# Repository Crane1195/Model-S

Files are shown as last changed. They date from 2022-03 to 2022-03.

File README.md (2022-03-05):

# Model-S
This circuit board is a complete solution for making custom all digital GameCube controllers without soldering.

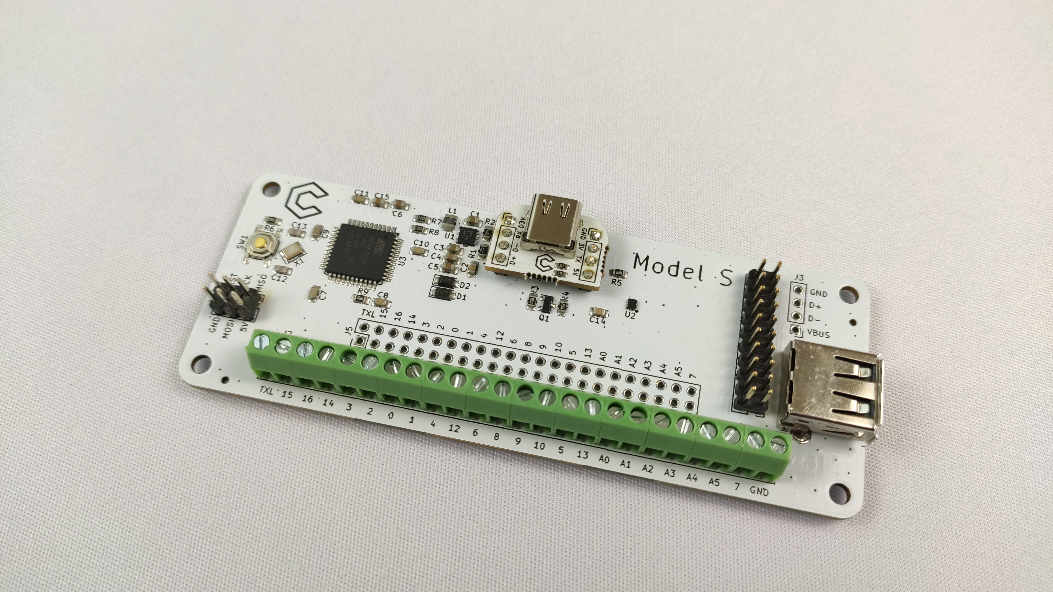
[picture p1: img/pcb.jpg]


## Features
- Connects to GameCube/Wii/GCC to USB adapter using the USB-C to GameCube cables that are sold on the Frame1 and the B0XX websites
- Connect buttons with screw terminals or 2.54mm pitch through holes
- Easily connect to a Brook Board to use the controller on PlayStation/Xbox/other consoles, with both boards sharing the Model S USB-C port
- Can be powered with just 3.3V, allowing the board to work on Mayflash adapters without the gray USB cable as well as GameCube/Wii consoles with faulty rumble lines

## Resources

User Manual - https://www.craneslab.xyz/manuals/s

Firmware - https://github.com/Crane1195/CL-FW

Questions - https://craneslab.xyz/discord

## License
This project is licenced under the GNU GPL Version 3. [See the included LICENSE file for details](LICENSE).

## Support my work
I set up a donation link for people who appreciate my work and wish to donate. Donations are greatly appreciated, but are far from necessary:

https://www.paypal.com/donate/?hosted_button_id=NFDEML5FKR8N8

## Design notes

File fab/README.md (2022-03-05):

# Disclaimer

I used JLC to assemble these circuit boards, but they have made mistakes on every single batch.

On the final batch that I will ever make with them, 240 Model S v2.3's, they ruined 142 of them.

JLC made several incorrect excuses as to why it was my fault, and refused to refund me. After two months of debating and gathering evidence, I got most of the money back through a PayPal dispute.

I will have the gerber/BOM/CPL files here for informational purposes only, but I do not advise using JLC.

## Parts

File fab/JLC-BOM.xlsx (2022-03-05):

Comment | Designator | Footprint | LCSC Part #
22uF | C1, C3-5 | 0805 | C45783
10nF | C2 | 0805 | C1710
4.7uF | C6 | 0805 | C1779
100nF | C7-11, C14 | 0805 | C49678
22pF | C12, C13 | 0805 | C1804
1uF | C15 | 0805 | C28323
MBR120 | D1, D2 | SOD-123 | C130880
1x4 Pin Headers | J1, J8 | HDR-TH_4P-P2.54-V | C124378
USB-A Female | J2 | USB-A-TH_USB-M-1_C2346 | C2346
2x3 Pin Headers | J4 | HDR-TH_6P-P2.54-V-R2-C3-S2.54 | C65114
2x10 Pin Headers | J6 | HDR-TH_20P-P2.54-V-M-R2-C10-S2.54 | C124359
Screw Terminals | J9-14 | CONN-TH_XY350V-3.5-4P | C557656
1uH | L1 | L2520 | C171753
BSS138 | Q1 | SOT-23-3 | C400505
402KΩ | R1 | 0805 | C17680
100KΩ | R2 | 0805 | C17407
10KΩ | R3-6, R9 | 0805 | C17414
22Ω | R7, R8 | 0805 | C17561
SW_PUSH | SW1 | SMD-SW-4_5.1x5.1x1.5 | C318884
TPS61230DRCR | U1 | VSON-10_EP_3.0x3.0x0.5P | C139626
TS3USB30ERSWR | U2 | UQFN-10_1.4x1.8x0.4P | C73880
ATMEGA32U4-AU | U3 | QFP-44_10.0x10.0x0.8P | C44854
16 Mhz XTAL | X1 | SMD-3225_4P | C70562

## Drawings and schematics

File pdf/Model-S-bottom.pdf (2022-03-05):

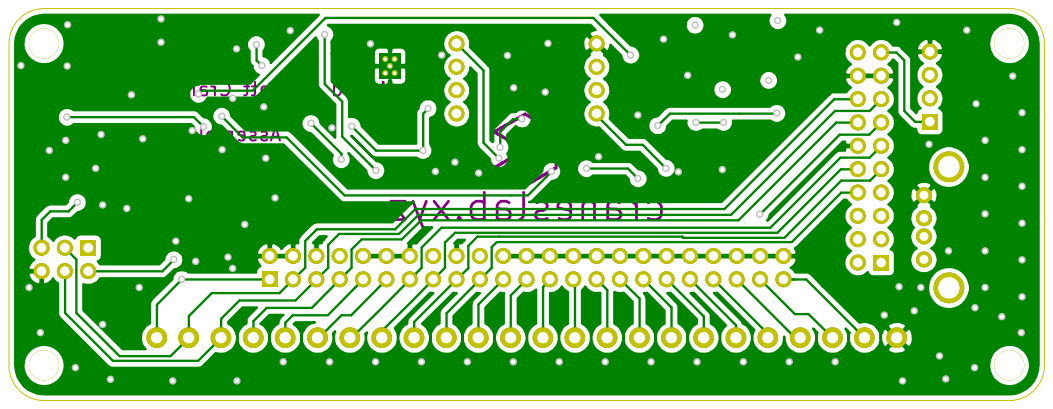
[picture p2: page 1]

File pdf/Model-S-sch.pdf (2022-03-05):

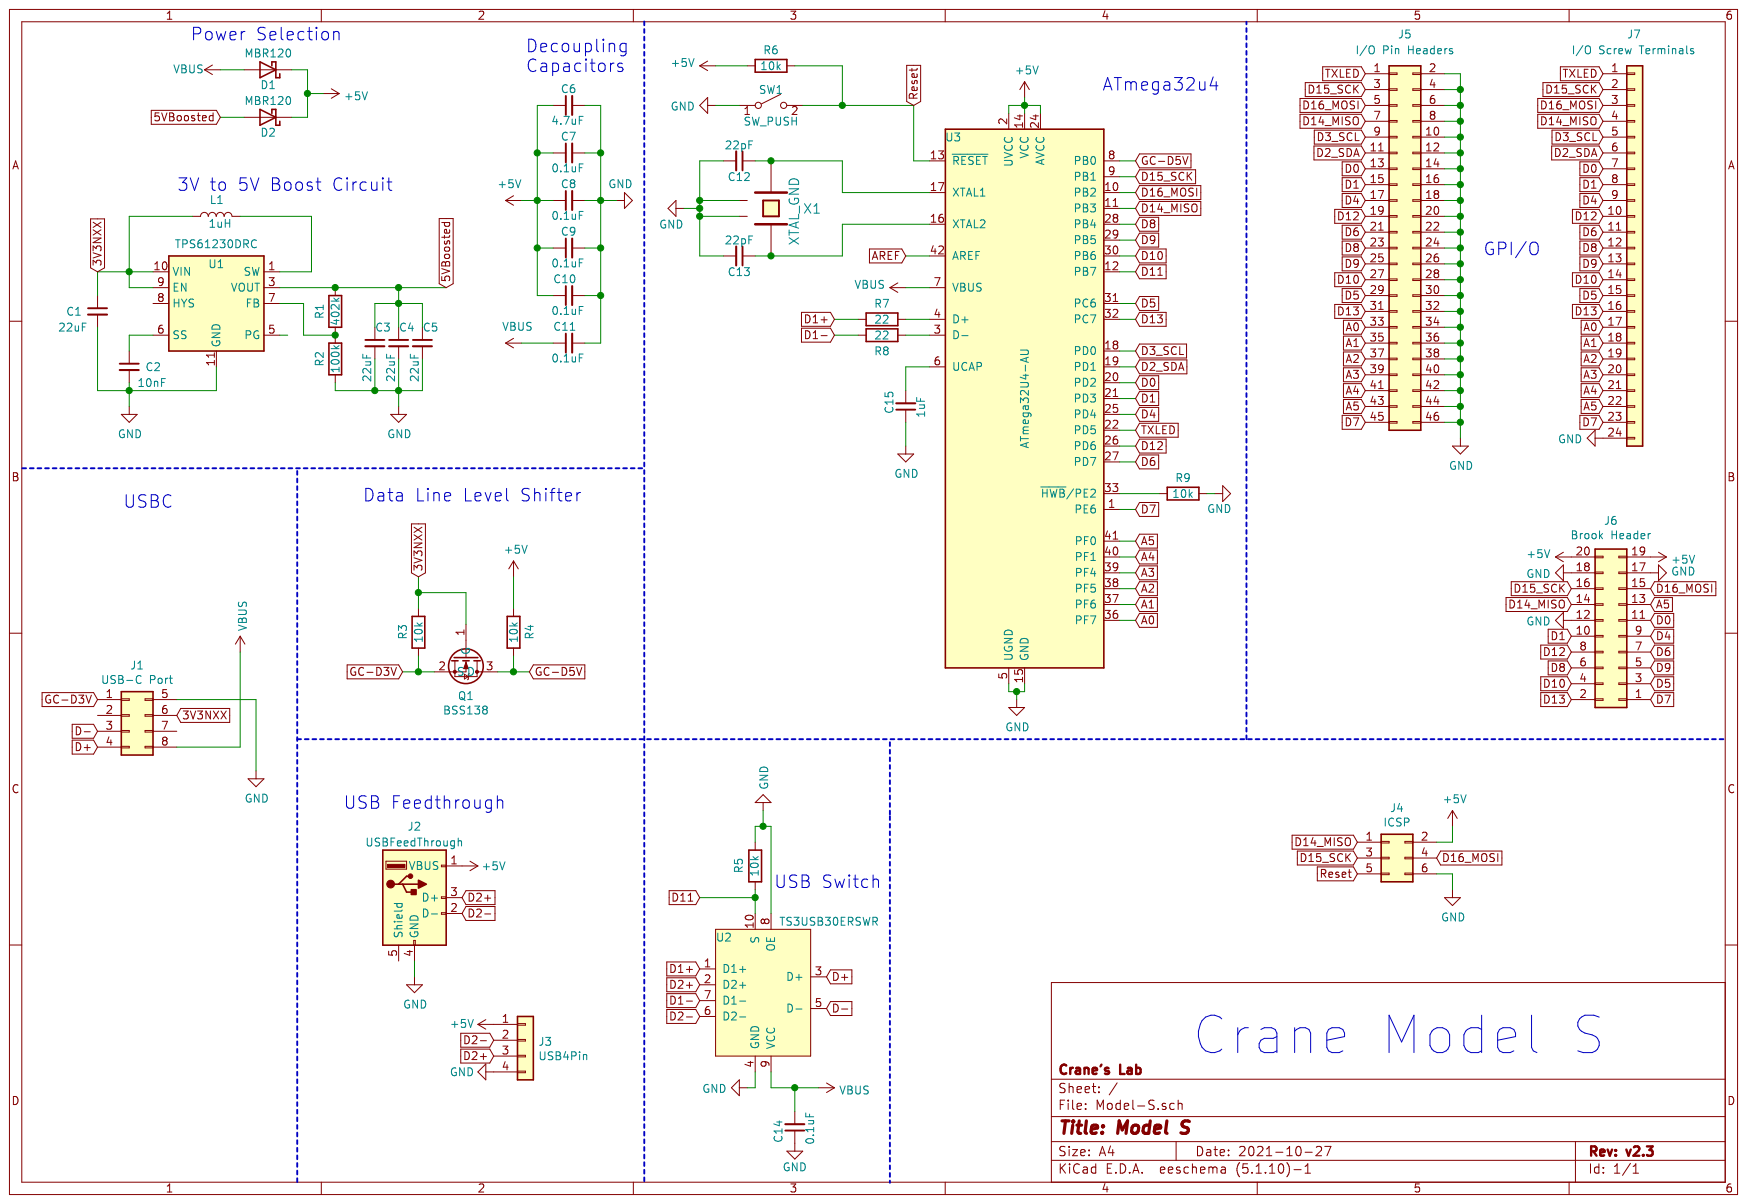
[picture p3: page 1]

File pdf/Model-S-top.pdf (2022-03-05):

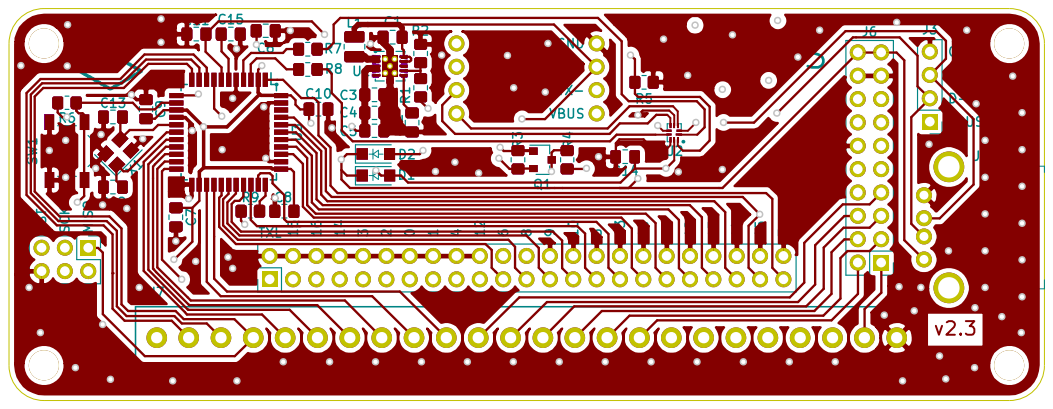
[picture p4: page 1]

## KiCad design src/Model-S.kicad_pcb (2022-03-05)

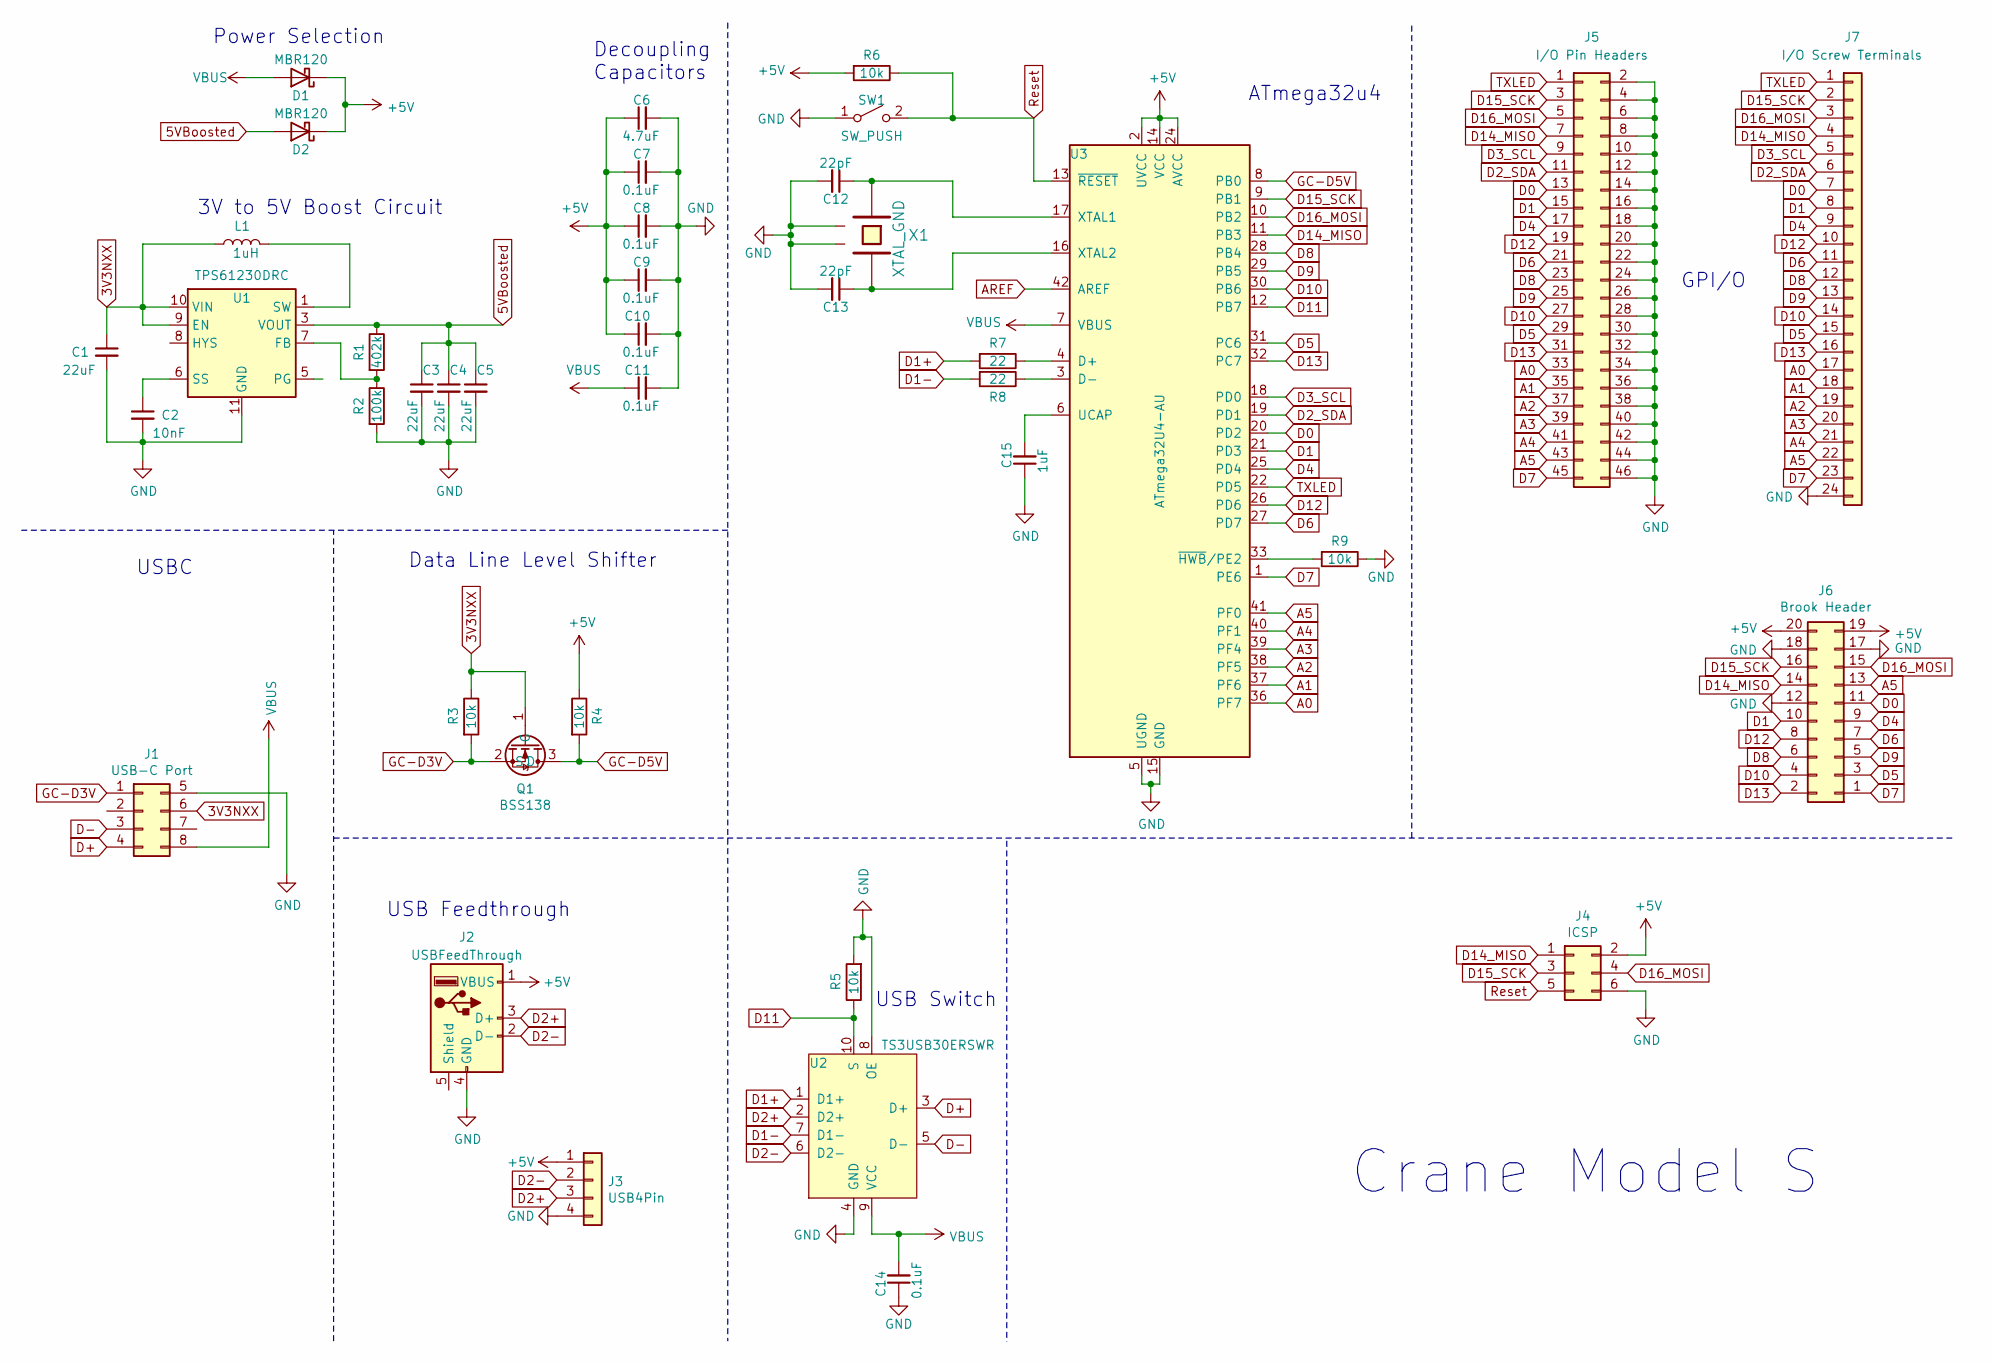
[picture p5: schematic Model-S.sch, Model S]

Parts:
C1, C3, C4, C5: 22uF; C_0805_2012Metric_Pad1.18x1.45mm_HandSolder
C2: 10nF; C_0805_2012Metric_Pad1.18x1.45mm_HandSolder
C6: 4.7uF; C_0805_2012Metric_Pad1.18x1.45mm_HandSolder
C7, C8, C9, C10, C11, C14: 0.1uF; C_0805_2012Metric_Pad1.18x1.45mm_HandSolder
C12, C13: 22pF; C_0805_2012Metric_Pad1.18x1.45mm_HandSolder
C15: 1uF; C_0805_2012Metric_Pad1.18x1.45mm_HandSolder
D1, D2: MBR120; D_SOD-123
J1: USB-C Port; Crane_USBC
J2: USBFeedThrough; USB_A_Female_UE27AC54100
J3: USB4Pin; PinHeader_1x04_P2.54mm_Vertical
J4: ICSP; PinHeader_2x03_P2.54mm_Vertical
J5: I/O Pin Headers; PinHeader_2x23_P2.54mm_Vertical
J6: Brook Header; PinHeader_2x10_P2.54mm_Vertical
J7: I/O Screw Terminals; 24PinScrewTerminal
L1: 1uH; L_1008_2520Metric
Q1: BSS138; SOT-23
R1: 402k; R_0805_2012Metric_Pad1.20x1.40mm_HandSolder
R2: 100k; R_0805_2012Metric_Pad1.20x1.40mm_HandSolder
R3, R4, R5, R6, R9: 10k; R_0805_2012Metric_Pad1.20x1.40mm_HandSolder
R7, R8: 22; R_0805_2012Metric_Pad1.20x1.40mm_HandSolder
SW1: SW_PUSH; SW_SPST_TL3342
U1: TPS61230DRC; Texas_S-PVSON-N10_ThermalVias
U2: TS3USB30ERSWR; UQFN-10_1.4x1.8mm_P0.4mm
U3: ATmega32U4-AU; TQFP-44_10x10mm_P0.8mm
X1: XTAL_GND; Crystal_SMD_TXC_7M-4Pin_3.2x2.5mm

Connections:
3V3NXX: C1.1, J1.6, L1.1, Q1.1 (G), R3.1, U1.9 (EN), U1.10 (VIN)
5VBoosted: C3.1, C4.1, C5.1, D2.2 (A), R1.1, U1.3 (VOUT), U1.4 (VOUT)
+5V: C6.1, C7.1, C8.1, C9.1, C10.1, D1.1 (K), D2.1 (K), J2.1 (VBUS), J3.1, J4.2, J6.19, J6.20, R4.1, R6.2, U3.2 (UVCC), U3.14 (VCC), U3.24 (AVCC), U3.34 (VCC), U3.44 (AVCC)
A0: J5.33, J7.17, U3.36 (PF7)
A1: J5.35, J7.18, U3.37 (PF6)
A2: J5.37, J7.19, U3.38 (PF5)
A3: J5.39, J7.20, U3.39 (PF4)
A4: J5.41, J7.21, U3.40 (PF1)
A5: J5.43, J6.13, J7.22, U3.41 (PF0)
AREF: U3.42 (AREF)
D0: J5.13, J6.11, J7.7, U3.20 (PD2)
D1: J5.15, J6.10, J7.8, U3.21 (PD3)
D1+: R7.2, U2.1 (D1+)
D1-: R8.2, U2.7 (D1-)
D2+: J2.3 (D+), J3.3, U2.2 (D2+)
D2-: J2.2 (D-), J3.2, U2.6 (D2-)
D2_SDA: J5.11, J7.6, U3.19 (PD1)
D3_SCL: J5.9, J7.5, U3.18 (PD0)
D4: J5.17, J6.9, J7.9, U3.25 (PD4)
D5: J5.29, J6.3, J7.15, U3.31 (PC6)
D6: J5.21, J6.7, J7.11, U3.27 (PD7)
D7: J5.45, J6.1, J7.23, U3.1 (PE6)
D8: J5.23, J6.6, J7.12, U3.28 (PB4)
D9: J5.25, J6.5, J7.13, U3.29 (PB5)
D10: J5.27, J6.4, J7.14, U3.30 (PB6)
D11: R5.1, U2.10 (S), U3.12 (PB7)
D12: J5.19, J6.8, J7.10, U3.26 (PD6)
D13: J5.31, J6.2, J7.16, U3.32 (PC7)
D14_MISO: J4.1, J5.7, J6.14, J7.4, U3.11 (PB3)
D15_SCK: J4.3, J5.3, J6.16, J7.2, U3.9 (PB1)
D16_MOSI: J4.4, J5.5, J6.15, J7.3, U3.10 (PB2)
D+: J1.4, U2.3 (D+)
D-: J1.3, U2.5 (D-)
GC-D3V: J1.1, Q1.2 (S), R3.2
GC-D5V: Q1.3 (D), R4.2, U3.8 (PB0)
GND: C1.2, C2.2, C3.2, C4.2, C5.2, C6.2, C7.2, C8.2, C9.2, C10.2, C11.2, C12.2, C13.2, C14.1, C15.1, J1.5, J2.4 (GND), J3.4, J4.6, J5.2, J5.4, J5.6, J5.8, J5.10, J5.12, J5.14, J5.16, J5.18, J5.20, J5.22, J5.24, J5.26, J5.28, J5.30, J5.32, J5.34, J5.36, J5.38, J5.40, J5.42, J5.44, J5.46, J6.12, J6.17, J6.18, J7.24, R2.2, R5.2, R9.1, SW1.1 (A), U1.11 (GND), U2.4 (GND), U2.8 (OE), U3.5 (UGND), U3.15 (GND), U3.23 (GND), U3.35 (GND), U3.43 (GND), X1.2, X1.4
unnamed: C2.1, U1.6 (SS)
unnamed: C12.1, U3.17 (XTAL1), X1.1
unnamed: C13.1, U3.16 (XTAL2), X1.3
unnamed: C15.2, U3.6 (UCAP)
unnamed: L1.2, U1.1 (SW), U1.2 (SW)
unnamed: R1.2, R2.1, U1.7 (FB)
unnamed: R7.1, U3.4 (D+)
unnamed: R8.1, U3.3 (D-)
unnamed: R9.2, U3.33 (~HWB~/PE2)
Reset: J4.5, R6.1, SW1.2 (B), U3.13 (~RESET)
TXLED: J5.1, J7.1, U3.22 (PD5)
VBUS: C11.1, C14.2, D1.2 (A), J1.8, U2.9 (VCC), U3.7 (VBUS)

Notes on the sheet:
Power Selection
ATmega32u4
GPI/O
USB Feedthrough
3V to 5V Boost Circuit
USB Switch
Data Line Level Shifter
Decoupling Capacitors
Crane Model S
USBC

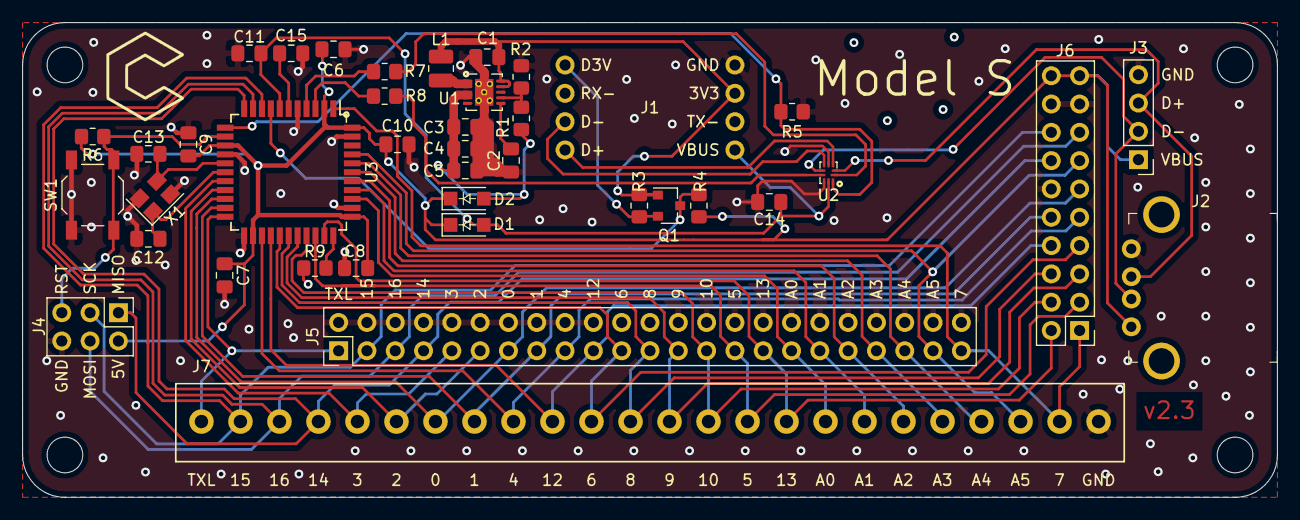
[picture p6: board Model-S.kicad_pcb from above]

Board: 2 copper layers, 112.6 x 42.6 mm, 40 parts (0 on the bottom side), 47 nets.

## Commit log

2022-03-05 GCCPCB 2.0
    [JLC-BOM.xlsx, Model-S.kicad_pcb, Model-S.sch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]
2022-03-05 Model S 2.1
    [JLC-BOM.xlsx, Model-S.kicad_pcb, Model-S.sch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]
2022-03-05 Model S 2.2
    [JLC-BOM.xlsx, Model-S.kicad_pcb, Model-S.sch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]
2022-03-05 Model S 2.3
    [JLC-BOM.xlsx, Model-S.kicad_pcb, Model-S.sch]
